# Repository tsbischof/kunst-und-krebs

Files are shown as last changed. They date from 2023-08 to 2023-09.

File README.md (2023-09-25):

# Kunst und Krebs

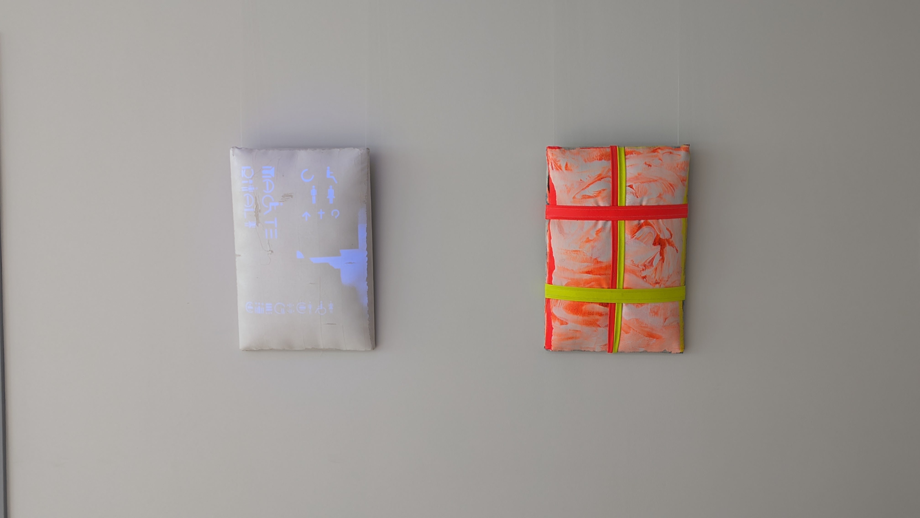
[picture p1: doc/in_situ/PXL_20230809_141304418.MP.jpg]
(https://www.youtube.com/watch?v=tSWUL30TMcM)

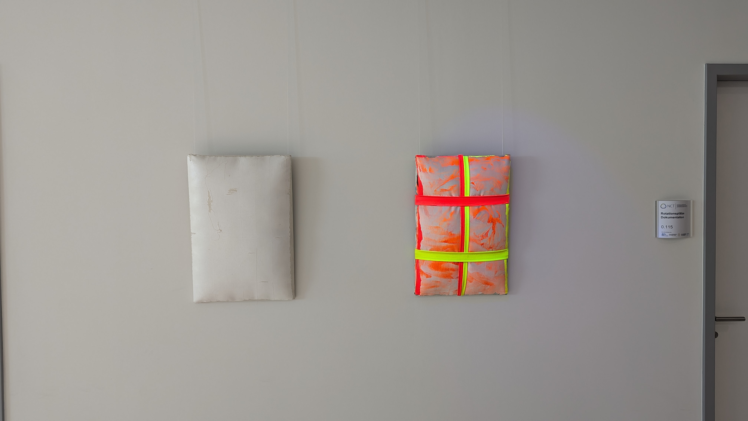
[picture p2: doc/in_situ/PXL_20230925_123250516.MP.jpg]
(https://www.youtube.com/watch?v=tSWUL30TMcM)


See [here](https://www.youtube.com/watch?v=tSWUL30TMcM) for a video of the exhibition.

The project files for lighting as part of the Kunst und Krebs exhibition, installed in NCT Dresden from 2023-2024.
This consists of:

* bill of materials for the hardware
* software used in modulation

The goal of this lighting is to:

* provide sufficient UV (395nm) illumination of the piece to generate visible amounts of fluorescence under normal lighting conditions
* modulate the amount of fluorescence generated to match a chosen pattern.
In this case we are emulating the cadence of human breathing

## Overview
See the `doc/` folder for all part documentation, system bill of materials, and photos of the completed system.

## Electronics
We built the lighting around LED modules from Thorlabs and an Arduino Nano for modulation.

The intended connection is:

* LEDD1B 0 -> GND, Pin 10
* LEDD1B 1 -> GND, Pin 11

Once programmed, the Nano can be powered and will automatically run the program.

## Developers
The Arduino code can be built and deployed using the Arduino IDE (https://www.arduino.cc/en/software/).
Follow the instructions at that URL to get started on your platform.

The main code is in `breathe/` and consists of:
* `breathe.ino`, which sets the output of the two LEDs based on a look-up table
* `make_signal.py`, which produces the look-up table in `breath.h`

The dependencies for the Python code are given in `requirements.txt`. 
You can build the look-up table by:
```
python3 -m venv venv
source venv/bin/activate
pip install -r requirements.txt
cd breathe
python make_signal.py
```

### Tools for assembly
To make modifications you will need the following:

* #2 Phillips tip screwdriver
* Thorlabs adjustable spanner wrench (SPW801)
* half-round file
* box knife
* metric hex wrench set (minimum: 1.2mm, 5mm)

## Press

* [Announcement](https://tu-dresden.de/kustodie/die-einrichtung/aktuelles/news/kunst-und-krebs-ausschreibung-fuer-meisterschueler-innen-der-hfbk-dresden)
* [Project page](https://www.nct-dresden.de/das-nctucc-dresden/newsroom/veranstaltungen/ausstellung-kunst-und-krebs.html)

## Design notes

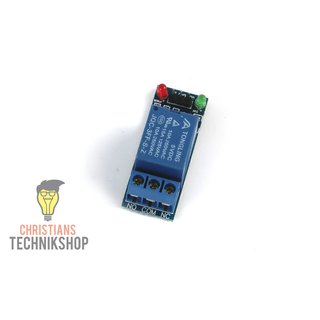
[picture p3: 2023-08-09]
doc/christians_technikshop/100381/Nano V3.0 Prototype Shield mehr Inputs und Outputs am Arduino Nano,_files/1-kanal-5v-relay-relais-modul-10a-250vac.jpg

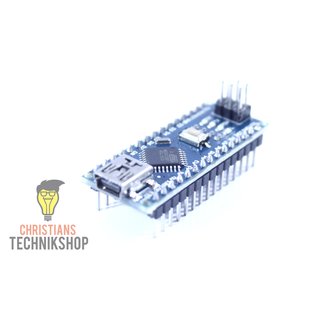
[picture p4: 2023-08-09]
doc/christians_technikshop/100381/Nano V3.0 Prototype Shield mehr Inputs und Outputs am Arduino Nano,_files/nano-v3-verloetet-entwicklerboard-fuer-arduino-ide-atmel_002.jpg

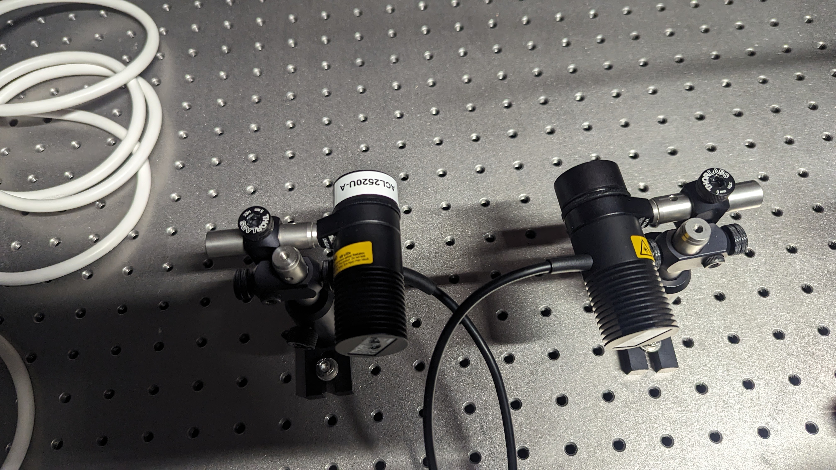
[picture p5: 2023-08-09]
doc/box/PXL_20230809_095255203.MP.jpg

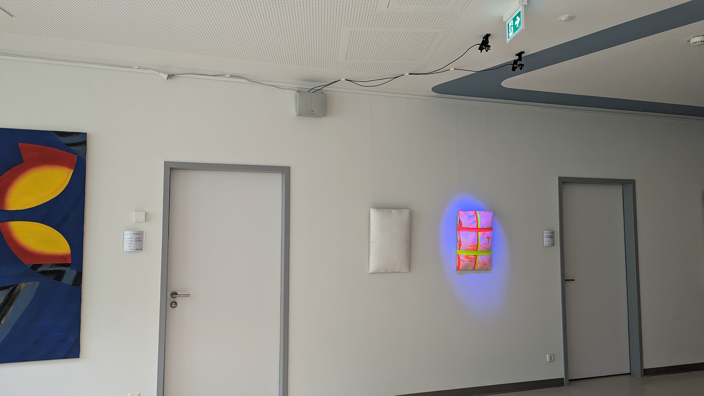
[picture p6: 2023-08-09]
doc/in_situ/PXL_20230809_141244423.MP.jpg

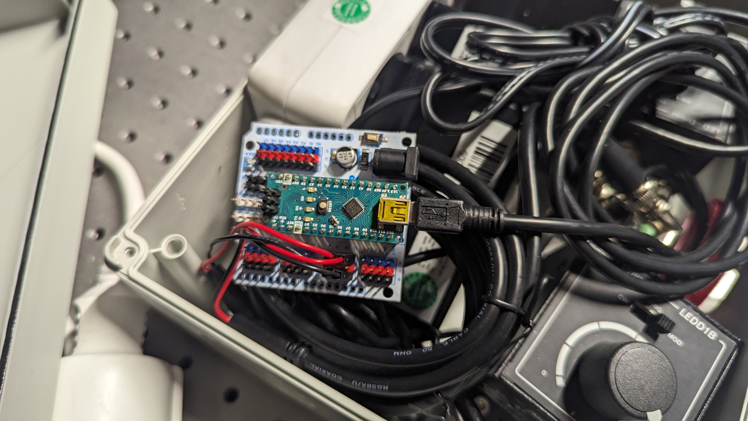
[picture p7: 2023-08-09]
doc/box/PXL_20230809_095502506.MP.jpg

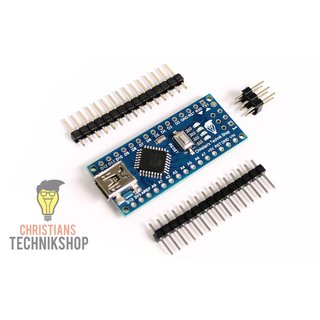
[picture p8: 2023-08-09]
doc/christians_technikshop/100381/Nano V3.0 Prototype Shield mehr Inputs und Outputs am Arduino Nano,_files/nano-v3-entwicklerboard-fuer-arduino-ide-atmel-atmega328p-av.jpg

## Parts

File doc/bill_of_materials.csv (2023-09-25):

Vendor | Part number | Quantity | Description
Thorlabs | LEDD1B | 2 | T-Cube LED Driver, 1200 mA Max Drive Current (Power Supply Not Included)
Thorlabs | KPS201 | 2 | 15 V, 2.66 A Power Supply Unit with 3.5 mm Jack Connector for One K- or T-Cube
Thorlabs | M395L5 | 2 | 395 nm, 1130 mW (Min) Mounted LED, 1000 mA
Thorlabs | LMR1S/M | 2 | Ø1" Lens Mount with Internal and External SM1 Threads, M4 Tap
Thorlabs | SM1V10 | 2 | Ø1" Adjustable Lens Tube, 0.81" Travel Range
Thorlabs | ACL2520U-A | 2 | Aspheric Condenser Lens, Ø25 mm, f=20.1 mm, NA=0.60 ARC: 350-700 nm
Thorlabs | SM1RR | 2 | SM1 Retaining Ring for Ø1" Lens Tubes and Mounts
Thorlabs | TR50/M | 2 | Ø12.7 mm Optical Post, SS, M4 Setscrew, M6 Tap, L = 50 mm
Thorlabs | TR75/M | 2 | Ø12.7 mm Optical Post, SS, M4 Setscrew, M6 Tap, L = 75 mm
 |  | 2 | M4 set screw, L = 10 mm
Thorlabs | PH50/M | 2 | Ø12.7 mm Post Holder, Spring-Loaded Hex-Locking Thumbscrew, L=50 mm
 |  | 2 | M6 cap screw, L = 10 mm
Thorlabs | SWC/M | 2 | Rotating Clamp for Ø1/2" Posts, 360° Continuously Adjustable, 5 mm Hex
Thorlabs | BA1/M | 2 | Mounting Base, 25 mm x 75 mm x 10 mm
Hirschmann | 933844001 | 2 | Hirschmann BNC-Messleitung Buchse / Stecker, Schwarz PVC-isoliert 1.2m, 60V dc
TE Connectivity | 5-1634526-1 | 2 | HF Adapter, BNC - BNC, 50Ω, Male - Weiblich, gewinkelt, 4GHz
Spelsberg | 82591001 | 1 | Verbindungsdose (L x B x H) 200 x 250 x 115mm Grau IP65
 |  | 1 | 3-fach 1.4m Kabel IP20 Steckerleise
Tesa | TE-000727-ST | 12 | tesa Powerstrips® Kabel-Clip
Tesa | TE-000451-ST | 2 | tesa® Klebestreifen für Fliesen und Metall (3kg)
Arduino | A000005 | 1 | Arduino Nano
Christian’s Technikshop | 100381 | 1 | Nano V3.0 Prototype Shield | mehr Inputs und Outputs am Arduino Nano
Voltcraft | VC-11342765 | 1 | VOLTCRAFT QCP-3000 VC-11342765 USB-Ladegerät Steckdose Ausgangsstrom (max.) 3000 mA 1 x USB Qualcomm Quick Charge 3.0
 |  | 1 | USB A to USB 2 mini, L=1m
 |  | 1 | 5m Schuko extension cable
 |  | 1 | cable management spiral, white

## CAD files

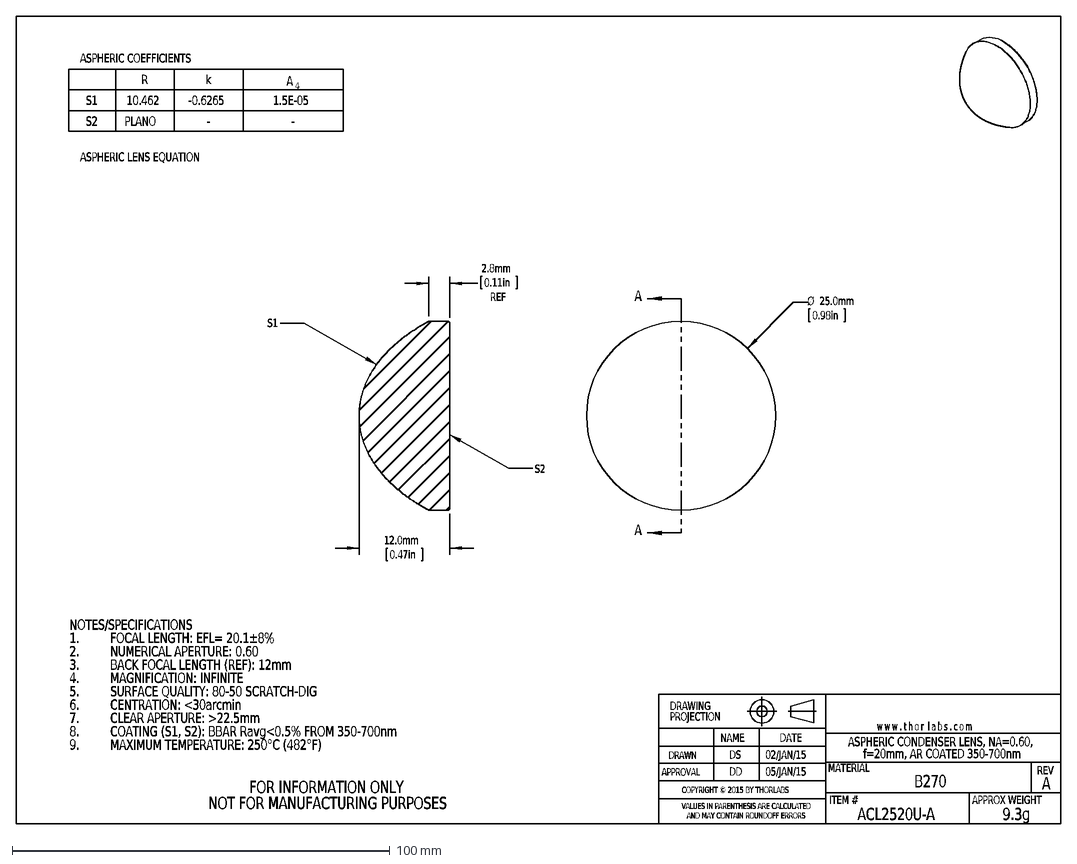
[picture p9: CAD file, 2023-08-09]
doc/thorlabs/ACL2520UA/ACL2520U-A-AutoCADDXF.dxf
NOTES/SPECIFICATIONS
FOCAL LENGTH: EFL= 20.1±8%
1.
NUMERICAL APERTURE: 0.60
2.
BACK FOCAL LENGTH (REF): 12mm
3.
MAGNIFICATION: INFINITE
4.
SURFACE QUALITY: 80-50 SCRATCH-DIG
5.
CENTRATION: <30arcmin
6.
CLEAR APERTURE: >22.5mm
7.
COATING (S1, S2): BBAR Ravg<0.5% FROM 350-700nm
8.
MAXIMUM TEMPERATURE: 250°C (482°F)
9.
ASPHERIC LENS EQUATION
ASPHERIC COEFFICIENTS
A
ACL2520U-A
MATERIAL
DRAWN
APPROVAL
REV
DS
DD
02/JAN/15
DATE
05/JAN/15
w w w . t h o r l a b s . c o m
ITEM #
APPROX WEIGHT
B270
9.3g
VALUES IN PARENTHESIS ARE CALCULATED
AND MAY CONTAIN ROUNDOFF ERRORS
DRAWING
PROJECTION
NAME
FOR INFORMATION ONLY
NOT FOR MANUFACTURING PURPOSES
ASPHERIC CONDENSER LENS, NA=0.60,
f=20mm, AR COATED 350-700nm
COPYRIGHT © 2015 BY THORLABS
R
k
4
S1
10.462
-0.6265
1.5E-05
S2
PLANO
-
Ø
25.0mm
0.98in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

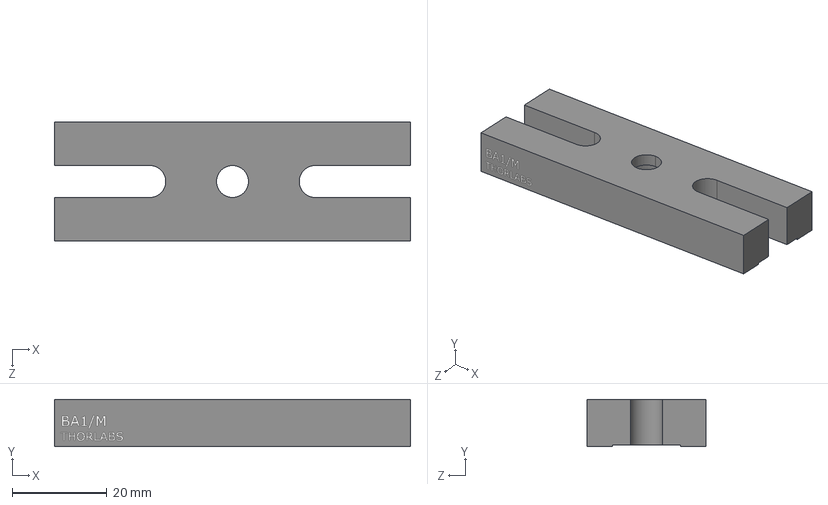
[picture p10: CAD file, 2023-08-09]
doc/thorlabs/BA1M/BA1_M-Step.step
75.0 x 10.0 x 25.0 mm

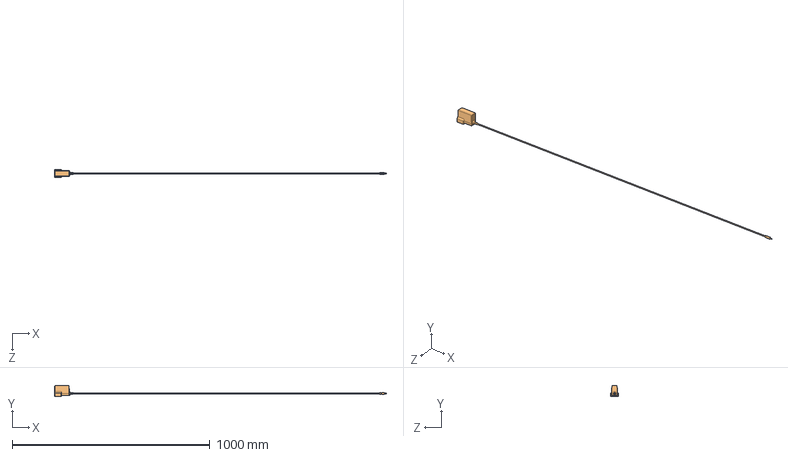
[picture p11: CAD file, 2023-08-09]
doc/thorlabs/KPS201/KPS201-Step.step
1680.5 x 57.0 x 39.1 mm

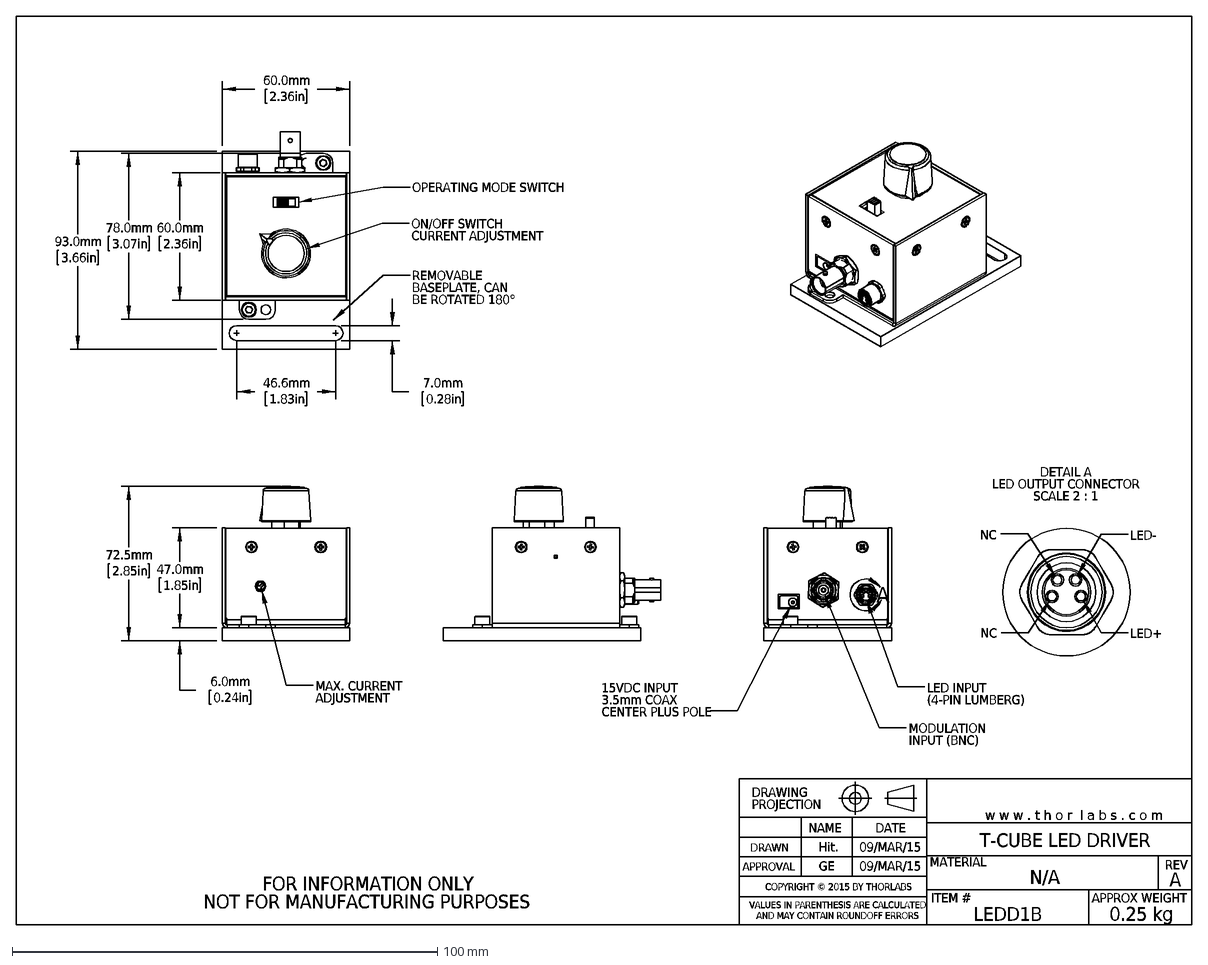
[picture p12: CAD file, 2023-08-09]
doc/thorlabs/LEDD1B/LEDD1B-AutoCADDXF.dxf
A
LEDD1B
MATERIAL
DRAWN
APPROVAL
REV
Hit.
GE
09/MAR/15
DATE
w w w . t h o r l a b s . c o m
ITEM #
APPROX WEIGHT
N/A
0.25 kg
VALUES IN PARENTHESIS ARE CALCULATED
AND MAY CONTAIN ROUNDOFF ERRORS
DRAWING
PROJECTION
NAME
FOR INFORMATION ONLY
NOT FOR MANUFACTURING PURPOSES
T-CUBE LED DRIVER
COPYRIGHT © 2015 BY THORLABS
93.0mm
3.66in
60.0mm
2.36in
78.0mm
3.07in
46.6mm
1.83in
7.0mm
0.28in
OPERATING MODE SWITCH
ON/OFF SWITCH
CURRENT ADJUSTMENT
REMOVABLE
BASEPLATE, CAN
BE ROTATED 180°
72.5mm
2.85in
6.0mm
0.24in
47.0mm
1.85in
MAX. CURRENT
ADJUSTMENT
15VDC INPUT
3.5mm COAX
CENTER PLUS POLE
LED INPUT
(4-PIN LUMBERG)
MODULATION
INPUT (BNC)
DETAIL A
LED OUTPUT CONNECTOR
SCALE 2 : 1
NC
LED-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

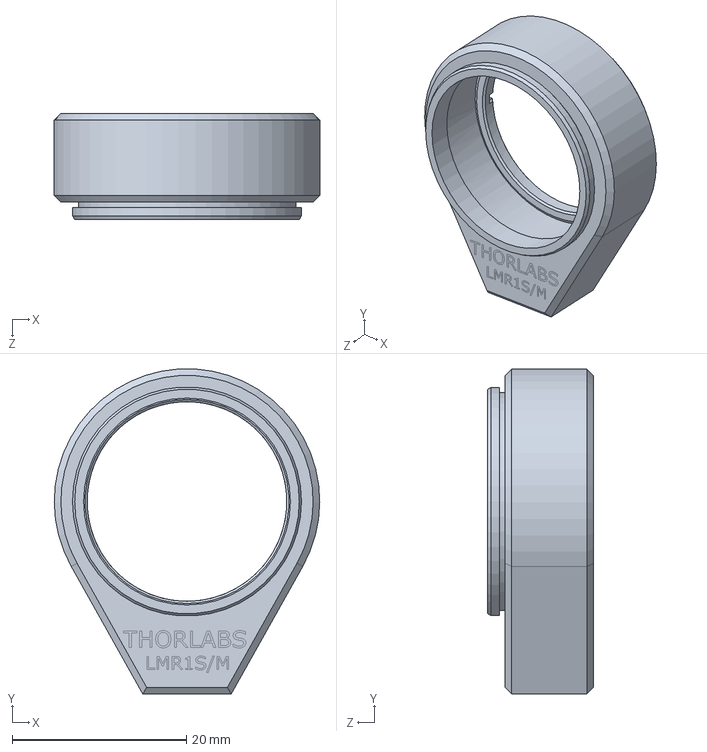
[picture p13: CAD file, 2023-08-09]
doc/thorlabs/LMR1SM/LMR1S_M-Solidworks.sldprt
30.5 x 37.3 x 12.2 mm

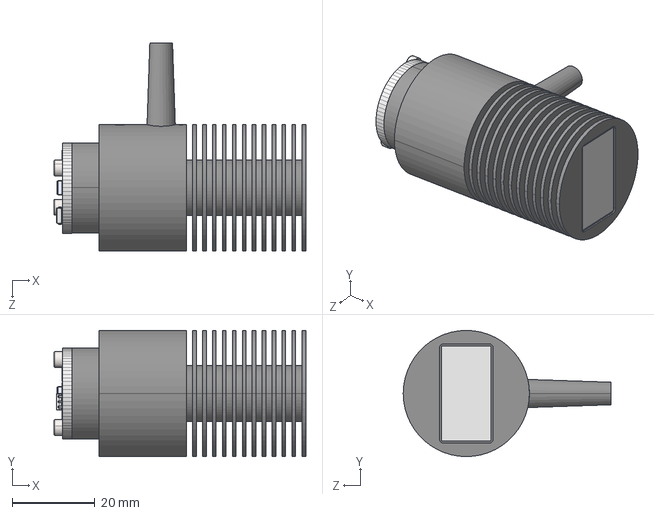
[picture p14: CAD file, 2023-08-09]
doc/thorlabs/M395L5/M395L5-Step.step
60.9 x 30.5 x 50.2 mm

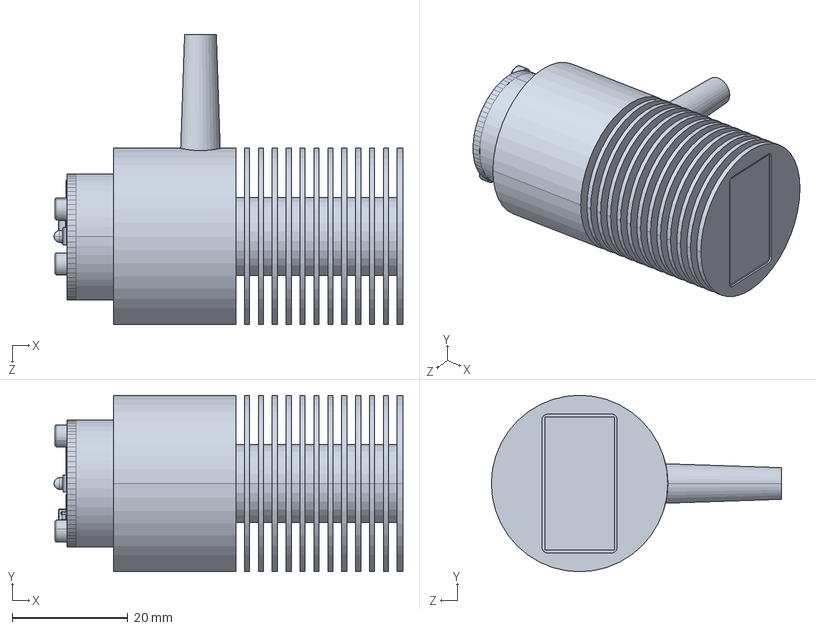
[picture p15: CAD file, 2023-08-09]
doc/thorlabs/M470L4/M470L4-Solidworks.sldprt
60.3 x 30.5 x 50.2 mm

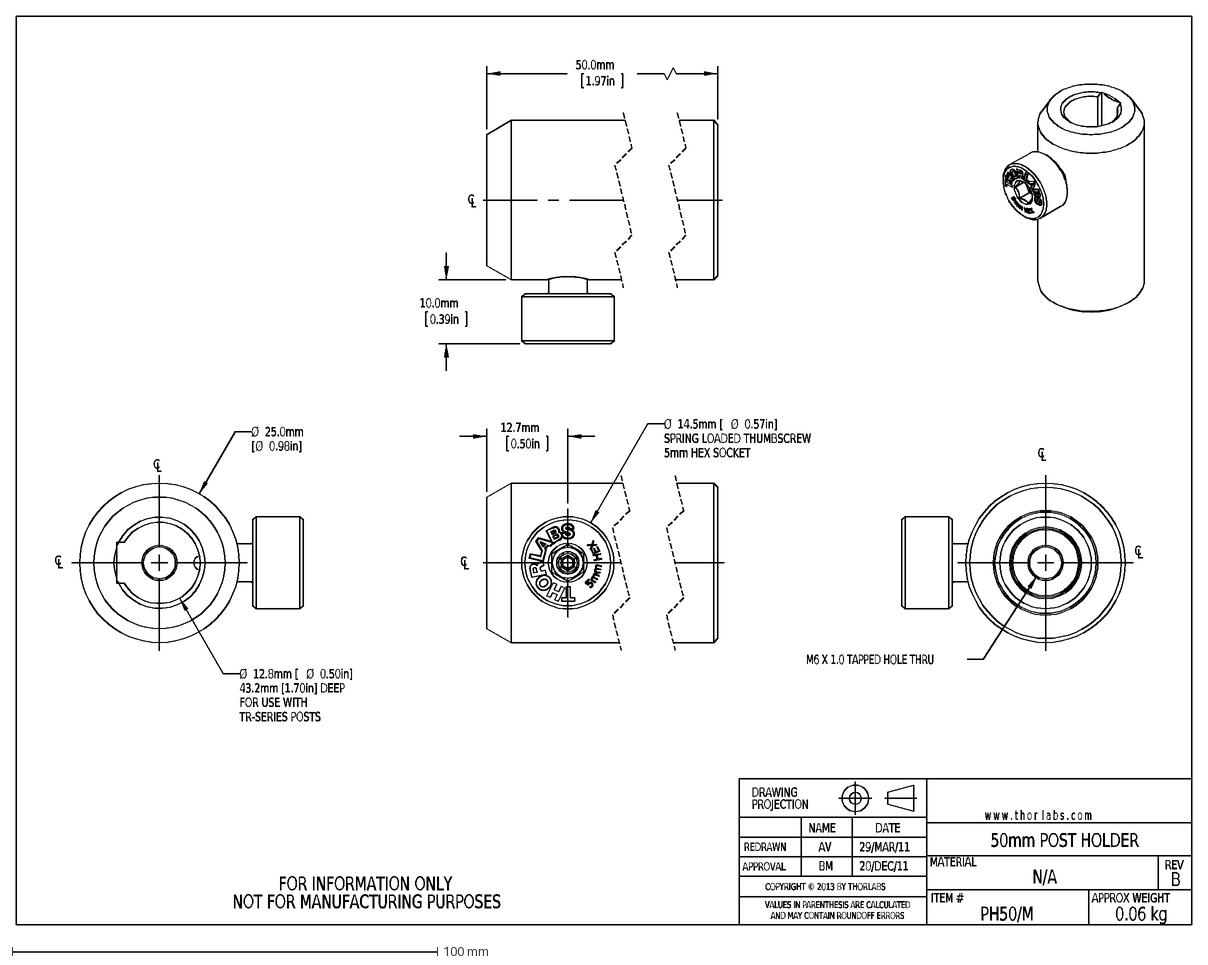
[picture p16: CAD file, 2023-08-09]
doc/thorlabs/PH50M/PH50_M-AutoCADDXF.dxf
B
PH50/M
MATERIAL
REDRAWN
APPROVAL
REV
AV
BM
29/MAR/11
DATE
20/DEC/11
w w w . t h o r l a b s . c o m
ITEM #
APPROX WEIGHT
N/A
0.06 kg
VALUES IN PARENTHESIS ARE CALCULATED
AND MAY CONTAIN ROUNDOFF ERRORS
DRAWING
PROJECTION
NAME
FOR INFORMATION ONLY
NOT FOR MANUFACTURING PURPOSES
50mm POST HOLDER
COPYRIGHT © 2013 BY THORLABS
12.7mm
0.50in
Ø
14.5mm [
0.57in]
SPRING LOADED THUMBSCREW
5mm HEX SOCKET
C
L
25.0mm
[
0.98in]
12.8mm [
0.50in]
43.2mm [1.70in] DEEP
FOR USE WITH
TR-SERIES POSTS
M6 X 1.0 TAPPED HOLE THRU
50.0mm
1.97in
10.0mm
0.39in

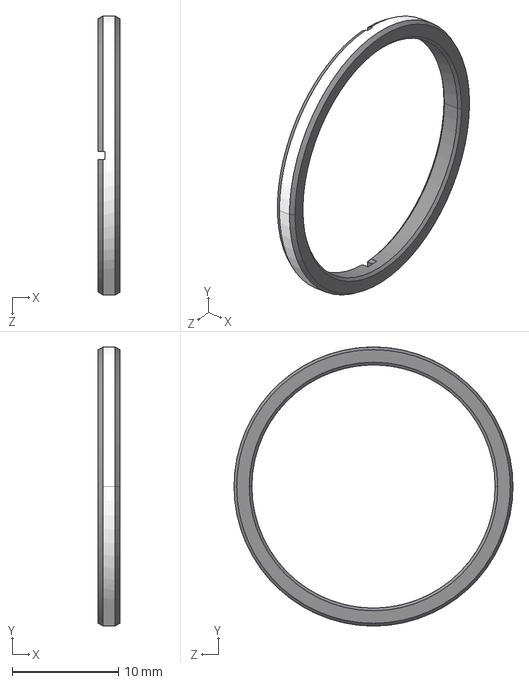
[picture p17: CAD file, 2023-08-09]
doc/thorlabs/SM1RR/SM1RR-Step.step
2.03 x 26.3 x 26.3 mm

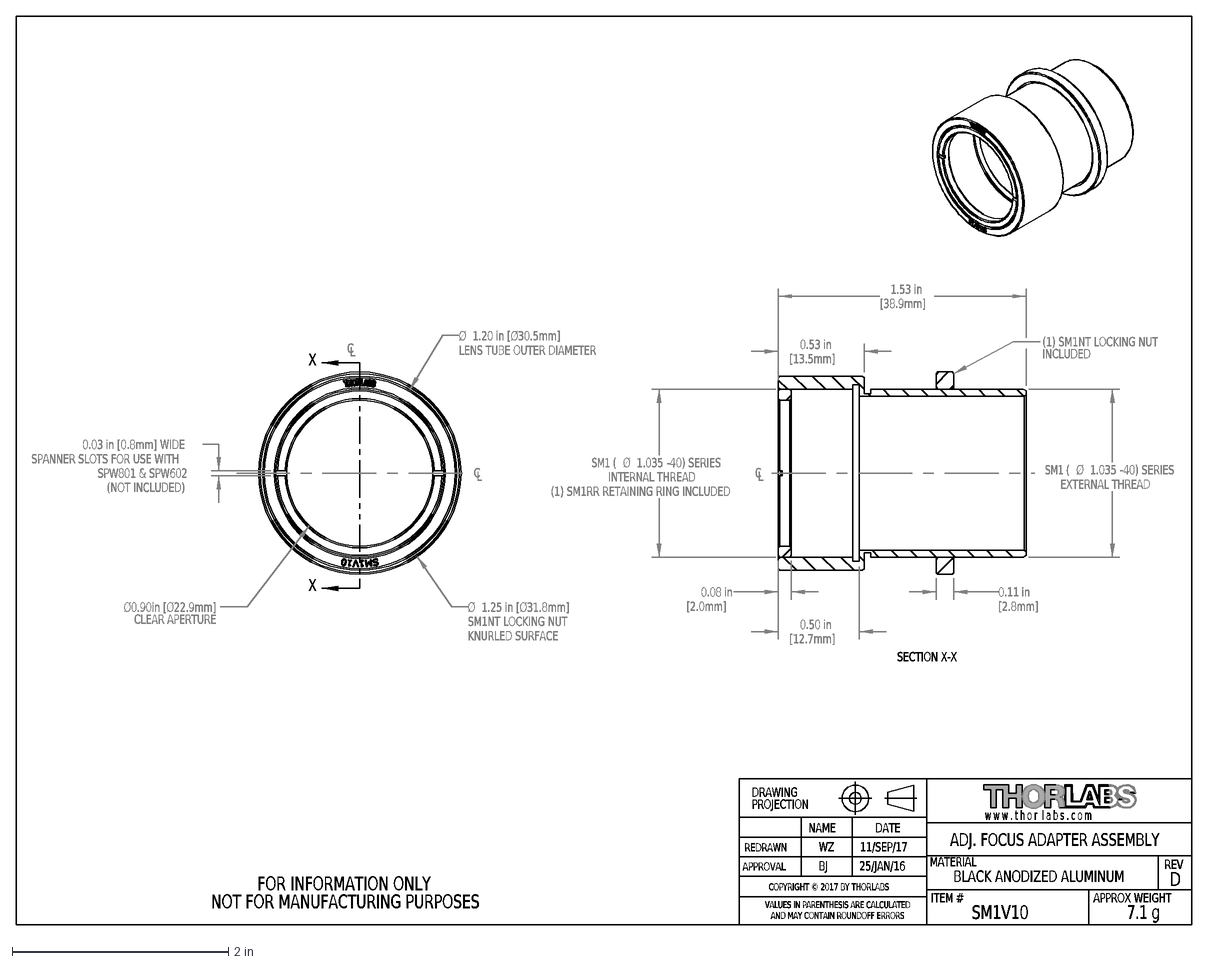
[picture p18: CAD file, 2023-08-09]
doc/thorlabs/SM1V10/SM1V10-AutoCADDXF.dxf
C
L
D
SM1V10
MATERIAL
REDRAWN
APPROVAL
REV
WZ
BJ
11/SEP/17
DATE
25/JAN/16
w w w . t h o r l a b s . c o m
ITEM #
APPROX WEIGHT
BLACK ANODIZED ALUMINUM
7.1 g
VALUES IN PARENTHESIS ARE CALCULATED
AND MAY CONTAIN ROUNDOFF ERRORS
DRAWING
PROJECTION
NAME
ADJ. FOCUS ADAPTER ASSEMBLY
COPYRIGHT © 2017 BY THORLABS
FOR INFORMATION ONLY
NOT FOR MANUFACTURING PURPOSES
Ø
1.25
in [Ø31.8mm]
SM1NT LOCKING NUT
KNURLED SURFACE
0.03
in [0.8mm] WIDE
SPANNER SLOTS FOR USE WITH
SPW801 & SPW602
(NOT INCLUDED)
1.20
in [Ø30.5mm]
LENS TUBE OUTER DIAMETER
Ø0.90in [Ø22.9mm]
CLEAR APERTURE
X
0.08
in
[2.0mm]
0.50
[12.7mm]
0.11
[2.8mm]
0.53
[13.5mm]
1.53
[38.9mm]
SM1 (
1.035
-40) SERIES
EXTERNAL THREAD
INTERNAL THREAD
(1) SM1RR RETAINING RING INCLUDED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

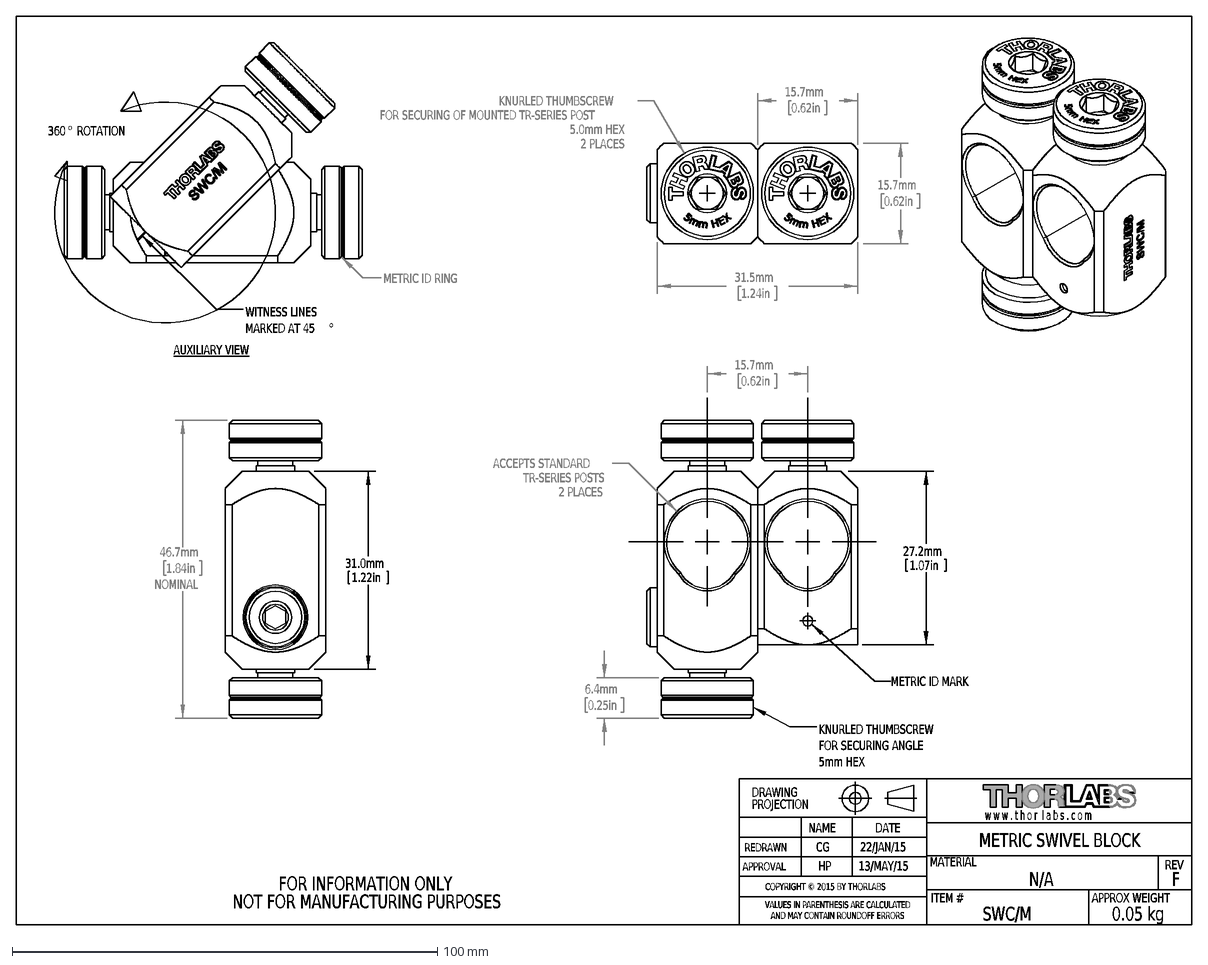
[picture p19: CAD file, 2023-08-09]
doc/thorlabs/SWCM/SWC_M-AutoCADDXF.dxf
F
SWC/M
MATERIAL
REDRAWN
APPROVAL
REV
CG
HP
22/JAN/15
DATE
13/MAY/15
w w w . t h o r l a b s . c o m
ITEM #
APPROX WEIGHT
N/A
0.05 kg
VALUES IN PARENTHESIS ARE CALCULATED
AND MAY CONTAIN ROUNDOFF ERRORS
DRAWING
PROJECTION
NAME
FOR INFORMATION ONLY
NOT FOR MANUFACTURING PURPOSES
METRIC SWIVEL BLOCK
COPYRIGHT © 2015 BY THORLABS
27.2mm
1.07in
ACCEPTS STANDARD
TR-SERIES POSTS
2 PLACES
15.7mm
0.62in
6.4mm
0.25in
METRIC ID MARK
KNURLED THUMBSCREW
FOR SECURING ANGLE
5mm HEX
31.0mm
1.22in
46.7mm
1.84in
NOMINAL
360
°
ROTATION
METRIC ID RING
AUXILIARY VIEW
WITNESS LINES
MARKED AT 45
31.5mm
1.24in
FOR SECURING OF MOUNTED TR-SERIES POST
5.0mm HEX

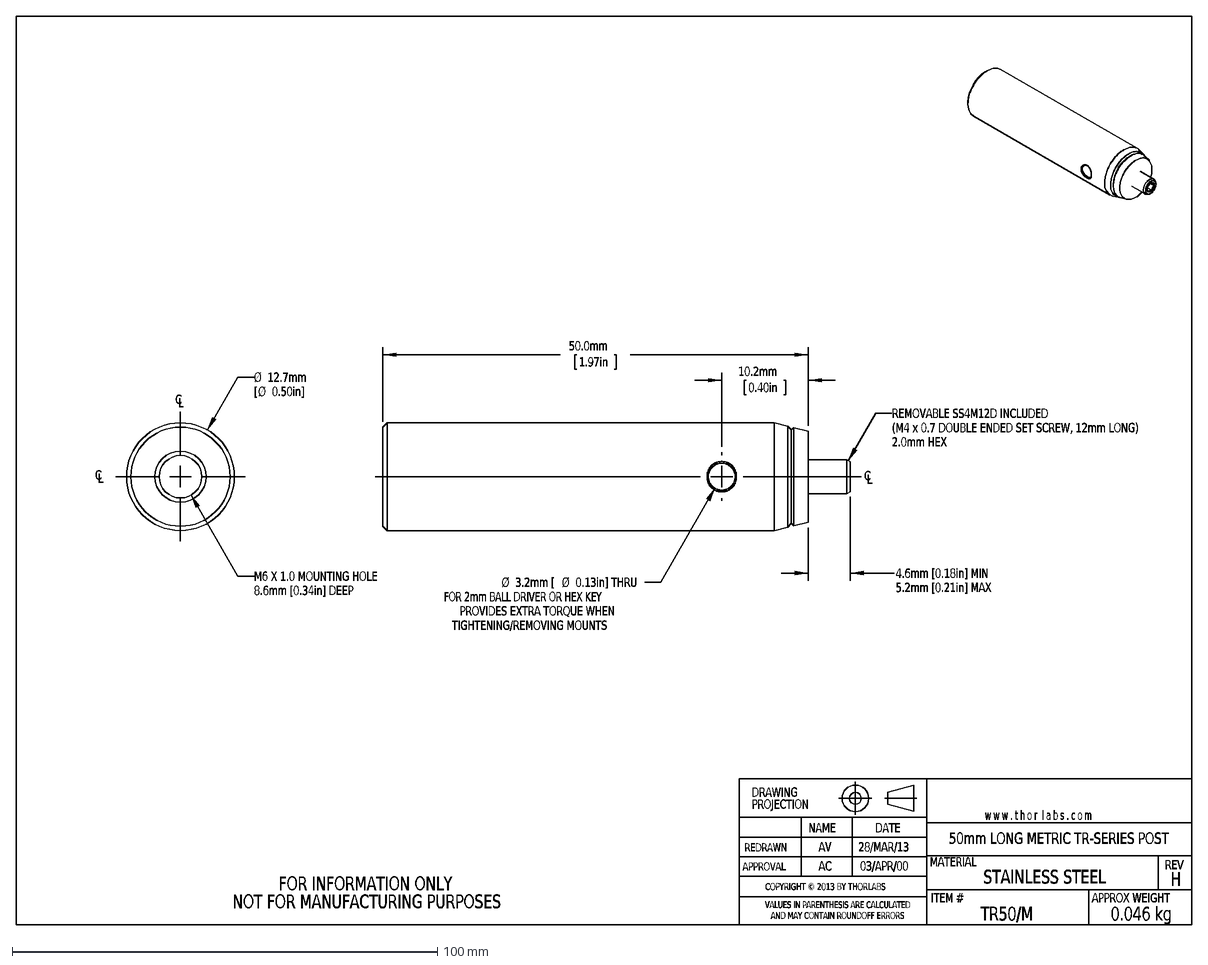
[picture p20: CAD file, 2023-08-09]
doc/thorlabs/TR50M/TR50_M-AutoCADDXF.dxf
H
TR50/M
MATERIAL
REDRAWN
APPROVAL
REV
AV
AC
28/MAR/13
DATE
03/APR/00
w w w . t h o r l a b s . c o m
ITEM #
APPROX WEIGHT
STAINLESS STEEL
0.046 kg
VALUES IN PARENTHESIS ARE CALCULATED
AND MAY CONTAIN ROUNDOFF ERRORS
DRAWING
PROJECTION
NAME
FOR INFORMATION ONLY
NOT FOR MANUFACTURING PURPOSES
50mm LONG METRIC TR-SERIES POST
COPYRIGHT © 2013 BY THORLABS
4.6mm [0.18in] MIN
5.2mm [0.21in] MAX
10.2mm
0.40in
50.0mm
1.97in
Ø
3.2mm [
0.13in] THRU
FOR 2mm BALL DRIVER OR HEX KEY
PROVIDES EXTRA TORQUE WHEN
TIGHTENING/REMOVING MOUNTS
REMOVABLE SS4M12D INCLUDED
(M4 x 0.7 DOUBLE ENDED SET SCREW, 12mm LONG)
2.0mm HEX
C
L
12.7mm
[
0.50in]
M6 X 1.0 MOUNTING HOLE
8.6mm [0.34in] DEEP

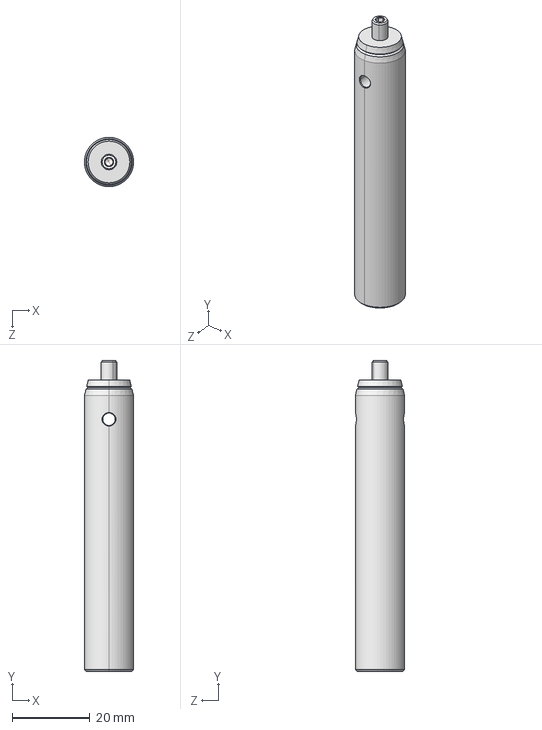
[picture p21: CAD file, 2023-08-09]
doc/thorlabs/TR75M/TR75_M-Step.step
12.7 x 80.0 x 12.7 mm

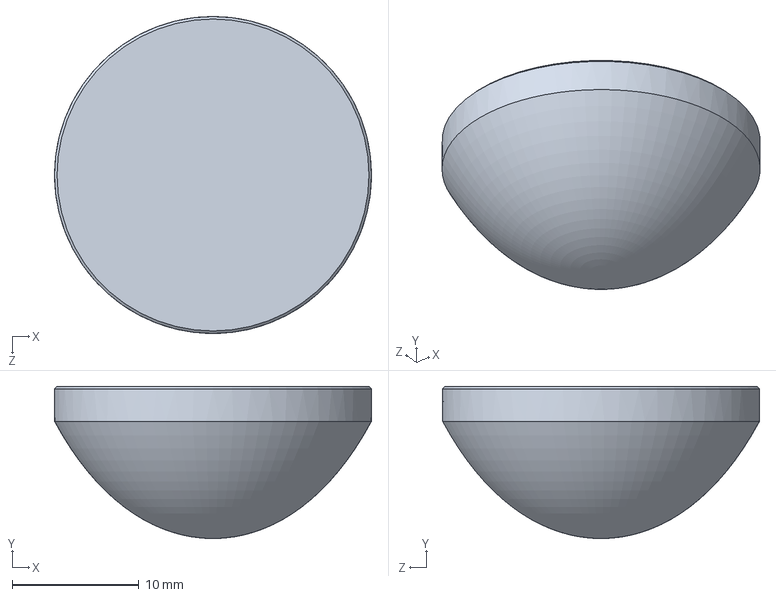
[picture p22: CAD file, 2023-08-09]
doc/thorlabs/ACL2520UA/ACL2520U-A-Solidworks.sldprt
25.0 x 12.0 x 25.0 mm

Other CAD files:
doc/spelsberg/82591001/M-490-925-01_V1.dwg
doc/thorlabs/BA1M/BA1_M-AutoCADDXF.dxf
doc/thorlabs/KPS201/KPS201-Solidworks.sldprt
doc/thorlabs/LEDD1B/LEDD1B-Solidworks.sldprt
doc/thorlabs/ACL2520UA/ACL2520U-A-Step.step
doc/thorlabs/BA1M/BA1_M-Solidworks.sldprt
doc/thorlabs/KPS201/KPS201-AutoCADDXF.dxf
doc/thorlabs/LMR1SM/LMR1S_M-AutoCADDXF.dxf
doc/thorlabs/LMR1SM/LMR1S_M-Step.step
doc/thorlabs/M395L5/M395L5-Solidworks.sldprt
doc/thorlabs/M470L4/M470L4-Step.step
doc/thorlabs/PH50M/PH50_M-Solidworks.sldprt
doc/thorlabs/PH50M/PH50_M-Step.step
doc/thorlabs/SM1RR/SM1RR-AutoCADDXF.dxf
doc/thorlabs/SM1RR/SM1RR-Solidworks.sldprt
doc/thorlabs/SM1V10/SM1V10-Solidworks.sldprt
doc/thorlabs/SM1V10/SM1V10-Step.step
doc/thorlabs/SWCM/SWC_M-Solidworks.sldprt
doc/thorlabs/TR50M/TR50_M-Solidworks.sldprt
doc/thorlabs/TR50M/TR50_M-Step.step
doc/thorlabs/TR75M/TR75_M-AutoCADDXF.dxf
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

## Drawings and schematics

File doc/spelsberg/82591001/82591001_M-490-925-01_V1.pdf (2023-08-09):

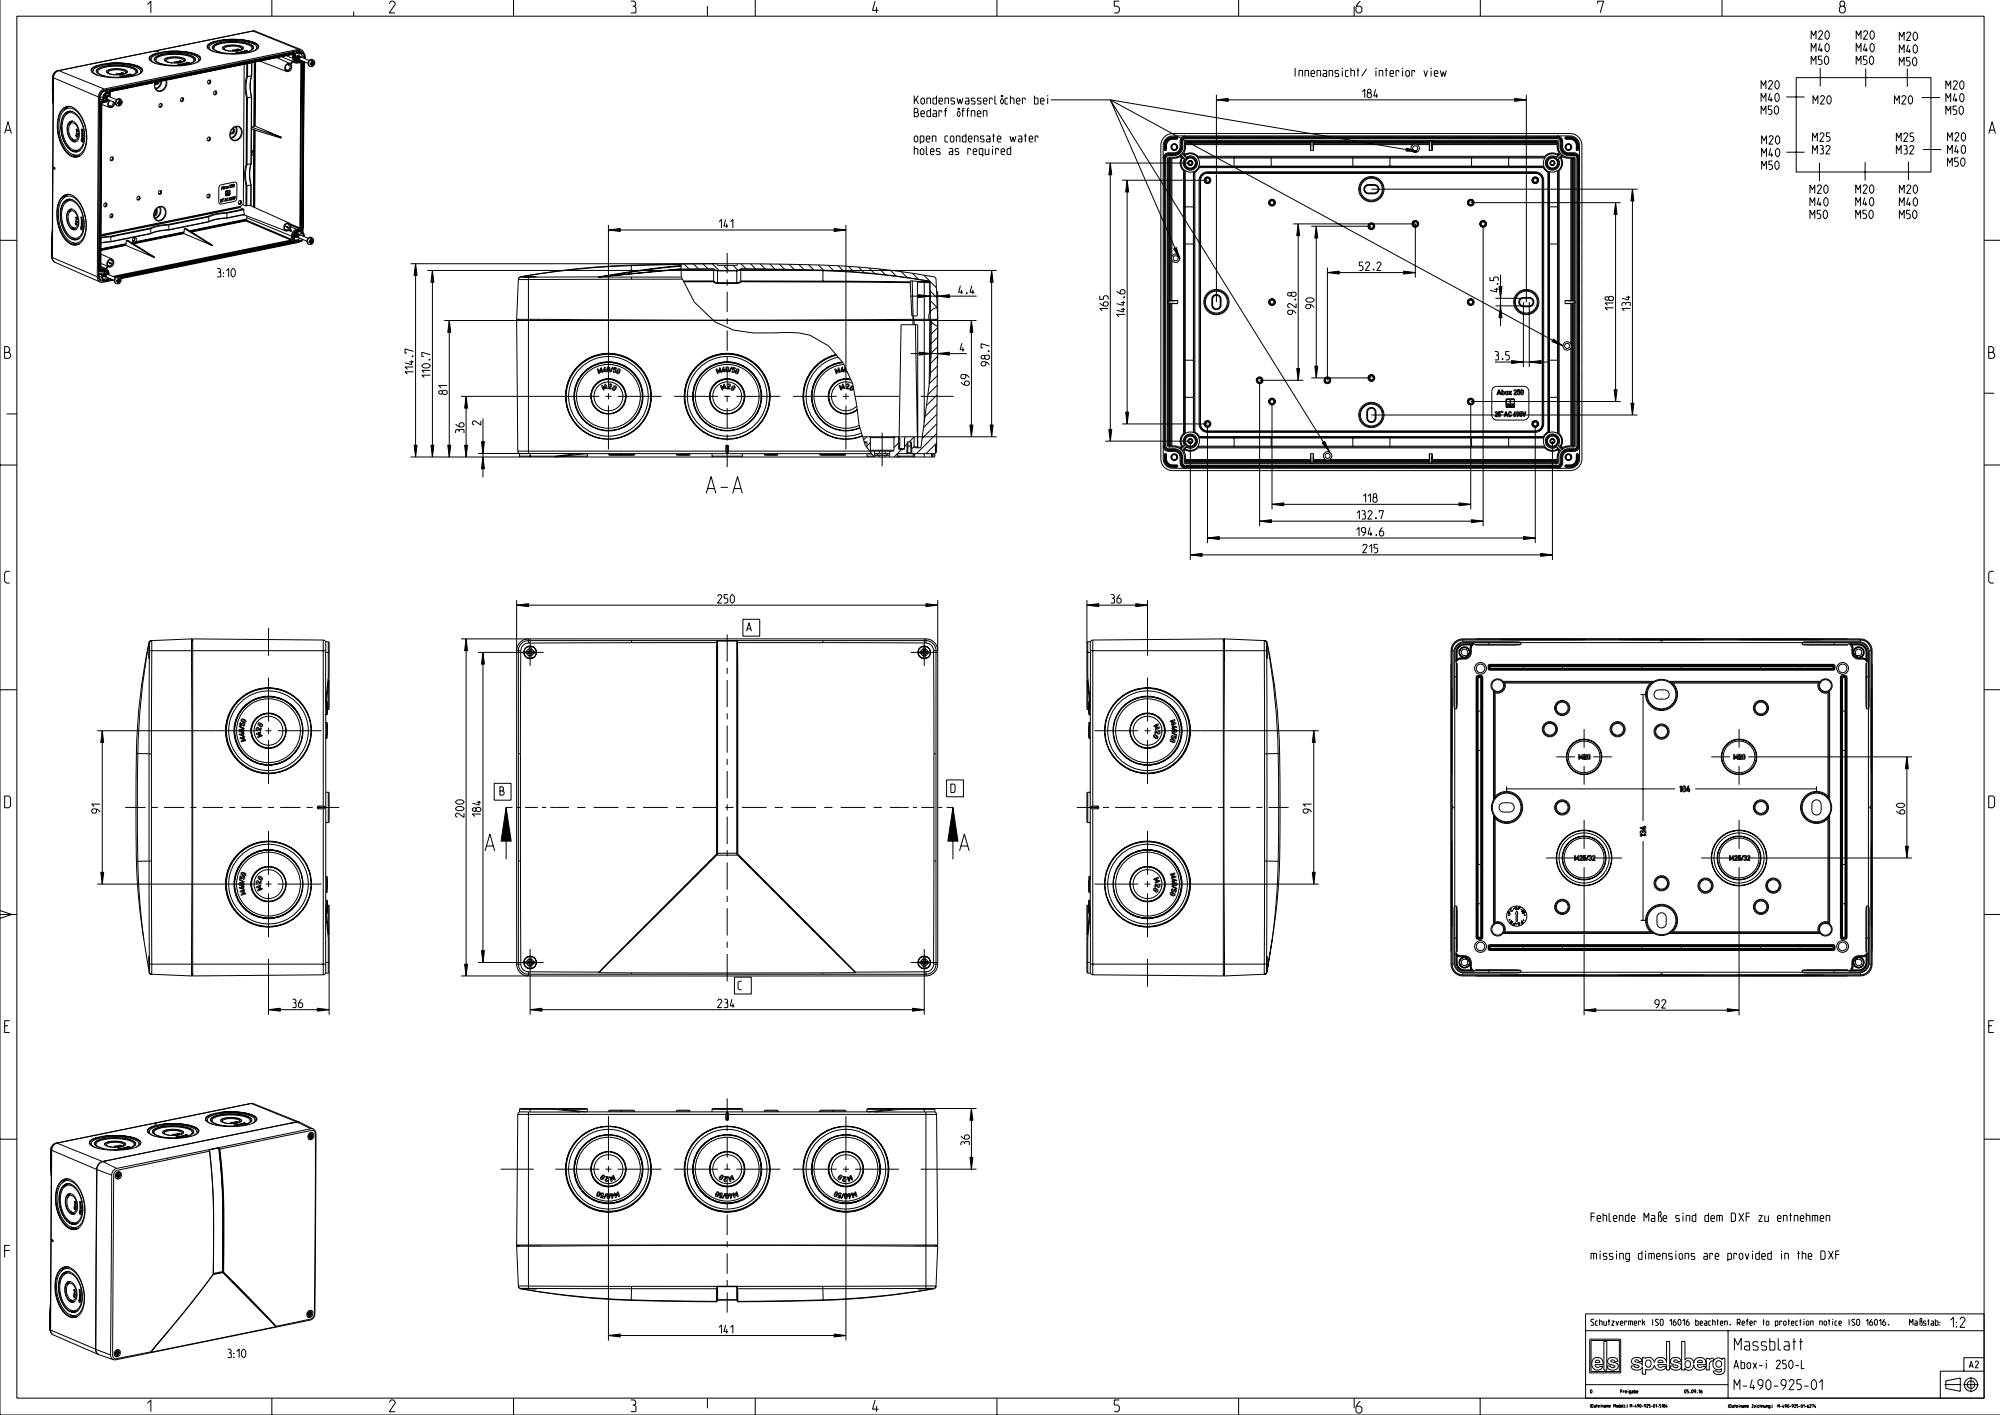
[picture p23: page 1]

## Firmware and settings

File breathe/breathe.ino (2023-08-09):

#include "breath.h"

const uint8_t wave0[] = BREATH;
const uint8_t led0 = 10;
const uint8_t wave1[] = BREATH;
const uint8_t led1 = 11;
const size_t signal_length = min(sizeof(wave0)/sizeof(uint8_t), sizeof(wave1)/sizeof(uint8_t));
const unsigned int duration_ms = 8000;
const unsigned int delay_between_leds_ms = 0;
const unsigned int delay_ms = (duration_ms) / signal_length;

void setup() {
  pinMode(led0, OUTPUT);
  analogWrite(led0, 0);
  pinMode(led1, OUTPUT);
  analogWrite(led1, 0);
  Serial.begin(9600);
  Serial.print("signal_length=");
  Serial.println(signal_length);
  Serial.print("duration_ms=");
  Serial.println(duration_ms);
  Serial.print("delay_ms=");
  Serial.println(delay_ms);
  Serial.print("delay_between_leds_ms=");
  Serial.println(delay_between_leds_ms);
}

void loop() {
  for (size_t i = 0; i < signal_length; i++) {
    analogWrite(led0, wave0[i]);
    delay(delay_ms);
  }
  delay(delay_between_leds_ms);
  for (size_t i = 0; i < signal_length; i++) {
    analogWrite(led1, wave1[i]);
    delay(delay_ms);
  }
  delay(delay_between_leds_ms);
}

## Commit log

2023-08-09 v1 as deployed onsite in NCT
    [ACL2520U-A-AutoCADDXF.dxf, ACL2520U-A-Solidworks.sldprt, ACL2520U-A-Step.step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]
2023-09-25 Resolve "Consider replacing the M470L4 with a M395L5"
    [bill_of_materials.csv]
